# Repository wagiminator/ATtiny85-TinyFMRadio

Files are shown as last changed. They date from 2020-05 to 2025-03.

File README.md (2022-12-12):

# TinyFMRadio - FM Radio with RDS based on ATtiny45/85
TinyFMRadio is an ATtiny45/85 controlled FM radio with RDS (RDA5807) with an integrated audio amplifier (XPT8871 or TC8871), an OLED display (SSD1306) and a rotary encoder. You can directly connect a protected li-ion battery, a 3W / 4Ω speaker and an FM antenna.

- Project Video (YouTube): https://youtu.be/dG5VVQmySEc
- Design Files (EasyEDA): https://easyeda.com/wagiminator/attiny85-tinyfmradio

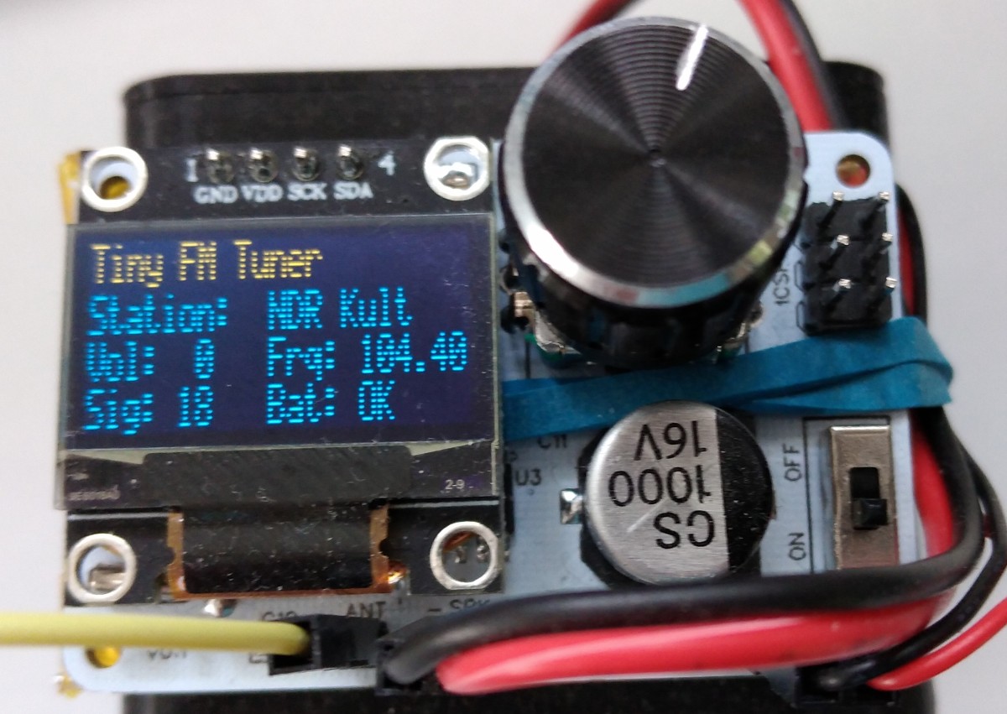
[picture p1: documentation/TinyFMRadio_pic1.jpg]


# Hardware
The low-cost RDA5807MP is a single-chip broadcast FM stereo radio tuner with fully integrated synthesizer, IF selectivity, RDS/RBDS and MPX decoder. The tuner uses the CMOS process, support multi-interface and require the least external component. All these make it very suitable for portable devices.

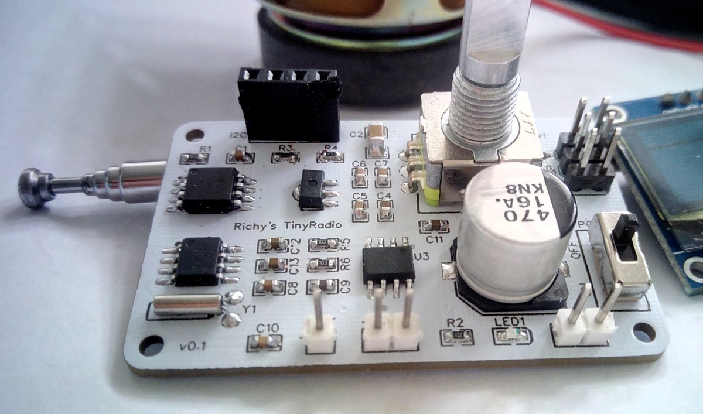
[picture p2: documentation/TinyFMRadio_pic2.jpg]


# Software
The firmware is just a demo sketch that implements basic functionality. By pressing the rotary encoder button the RDA5807 seeks the next radio station. Turning the rotary encoder increases/decreases the volume. Selected frequency and volume are stored in the EEPROM. Station name, frequency, signal strength, volume and battery state of charge are shown on an OLED display.

## I²C Implementation
The I²C protocol implementation is based on a crude bitbanging method. It was specifically designed for the limited resources of ATtiny10 and ATtiny13, but should work with some other AVRs as well. Due to the low clock frequency of the CPU, it does not require any delays for correct timing. In order to save resources, only the basic functionalities which are needed for this application are implemented. For a detailed information on the working principle of the I²C implementation visit [TinyOLEDdemo](https://github.com/wagiminator/attiny13-tinyoleddemo).

## Controlling the RDA5807
The FM tuner IC RDA5807MP is controlled via I²C by the ATtiny. It has six writable 16-bit registers (addresses 0x02 - 0x07) and six readable 16-bit registers (addresses 0x0A - 0x0F). The RDA5807 has two methods of write access, a sequential one in which the registers are always written starting from address 0x02 and an indexed method in which the register address is transferred first and then the content. Both methods are determined by different I²C addresses. To transfer the 16-bit register content, the high byte is sent first. The RDA5807 is controlled by setting or clearing certain bits in the respective registers. The details of the meanings of the individual registers can be found in the data sheet. The current register contents are saved in the RDA_regs arrays. The RDA implementation is based on the work of [Maarten Janssen](https://hackaday.io/project/9009-arduino-radio-with-rds).

## Rotary Encoder Implementation
The implementation for the rotary encoder uses pin change interrupts on only one of the pins and is written in such a way that bouncing is automatically suppressed.

## Compiling and Uploading the Software
### If using the Arduino IDE
- Make sure you have installed [ATtinyCore](https://github.com/SpenceKonde/ATTinyCore).
- Go to **Tools -> Board -> ATtinyCore** and select **ATtiny25/45/85 (No bootloader)**.
- Go to **Tools** and choose the following board options:
  - **Chip:**           ATtiny45 or ATtiny85
  - **Clock:**          1 MHz (internal)
  - **B.O.D.:**         disabled
  - Leave the rest at the default settings
- Connect your programmer to your PC and to the ICSP header of the device.
- Go to **Tools -> Programmer** and select your ISP programmer (e.g. [USBasp](https://aliexpress.com/wholesale?SearchText=usbasp)).
- Go to **Tools -> Burn Bootloader** to burn the fuses.
- Open TinyFMRadio sketch and click **Upload**.

### If using the precompiled hex-file
- Make sure you have installed [avrdude](https://learn.adafruit.com/usbtinyisp/avrdude).
- Connect your programmer to your PC and to the ICSP header of the device.
- Open a terminal.
- Navigate to the folder with the hex-file.
- Execute the following command (if necessary replace "t85" with your chip and "usbasp" with the programmer you use):
  ```
  avrdude -c usbasp -p t85 -U lfuse:w:0x62:m -U hfuse:w:0xd7:m -U efuse:w:0xff:m -U flash:w:tinyfmradio.hex
  ```

### If using the makefile (Linux/Mac)
- Make sure you have installed [avr-gcc toolchain and avrdude](http://maxembedded.com/2015/06/setting-up-avr-gcc-toolchain-on-linux-and-mac-os-x/).
- Connect your programmer to your PC and to the ICSP header of the device.
- Open a terminal.
- Navigate to the folder with the makefile and the Arduino sketch.
- Run `DEVICE=attiny85 PROGRMR=usbasp make install` to compile, burn the fuses and upload the firmware (change DEVICE and PROGRMR accordingly).

# References, Links and Notes
1. [ATtiny25/45/85 Datasheet](https://ww1.microchip.com/downloads/en/DeviceDoc/Atmel-2586-AVR-8-bit-Microcontroller-ATtiny25-ATtiny45-ATtiny85_Datasheet.pdf)
2. [RDA5807MP Datasheet](https://datasheet.lcsc.com/szlcsc/1806121226_RDA-Microelectronics-RDA5807MP_C167245.pdf)
3. [SSD1306 Datasheet](https://cdn-shop.adafruit.com/datasheets/SSD1306.pdf)
4. [TC8871 Datasheet](https://datasheet.lcsc.com/lcsc/2010160933_Shenzhen-Fuman-Elec-TC8871_C89482.pdf)
5. [ATtiny13 TinyPocketRadio](https://github.com/wagiminator/ATtiny13-TinyPocketRadio)

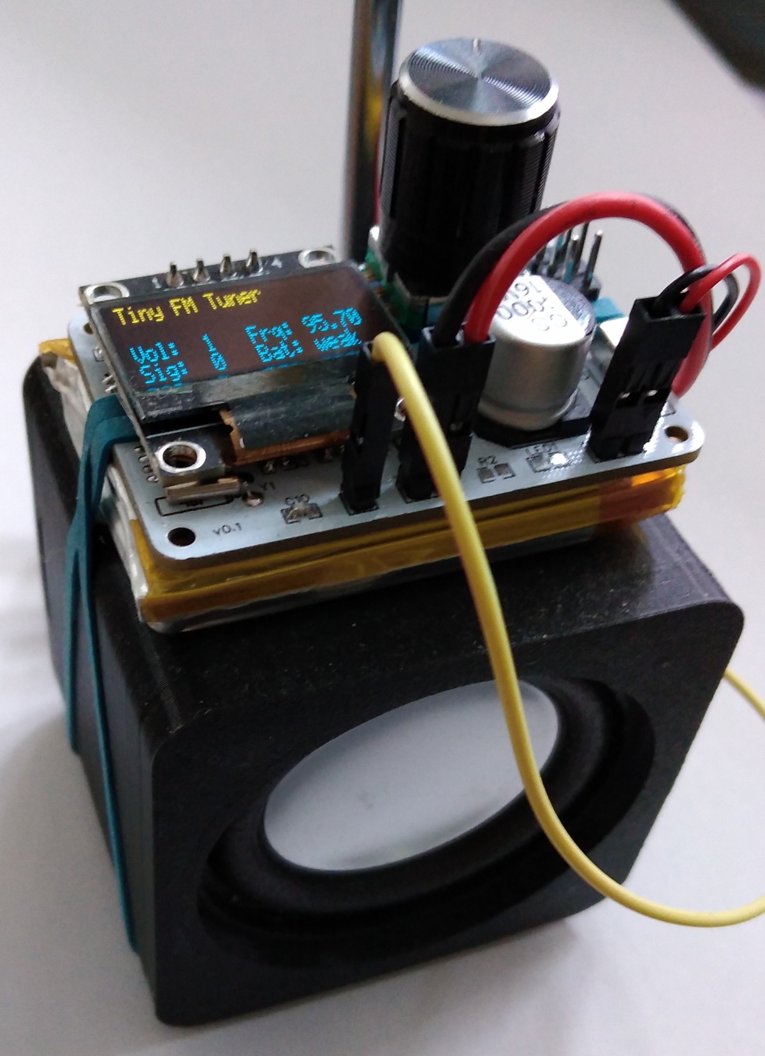
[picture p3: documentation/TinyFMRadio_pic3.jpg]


# License


This work is licensed under Creative Commons Attribution-ShareAlike 3.0 Unported License. 
(http://creativecommons.org/licenses/by-sa/3.0/)

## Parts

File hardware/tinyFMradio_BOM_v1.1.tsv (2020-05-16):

ID | Name | Designator | Footprint | Quantity | Manufacturer Part | Manufacturer | Supplier | Supplier Part | Mounted
1 | Header | VIN,SPK | HDR-1X2/2.54 | 2 | 2.54-1*2PFemale | BOOMELE | LCSC | C49661
2 | HT7333-A | U4 | SOT-89 | 1 | HT7333-A | HOLTEK | LCSC | C21583
3 | 32.768 khz | Y1 | XTAL-32KHZ | 1 | VT-200-F-32.768kHz-20PPM-6pF | Seiko | LCSC | C398715 | No
4 | I2C | I2C | HDR-4X1/2.54 | 1 | Header-Female-2.54_1x4 | ReliaPro | LCSC | C124413
5 | 1000uF | C3 | CAP-SMD_D10.0-L10.3-W10.3-H10.2 | 1 | EEE1CA471P | PANASONIC | LCSC | C336217
6 | 1k | R2 | 0603 | 1 | 0603WAF1001T5E | UniOhm | LCSC | C21190
7 | 10k | R7,R1,R8,R9 | 0603 | 4 | 0603WAF1002T5E | UniOhm | LCSC | C25804
8 | 20k | R6,R5 | 0603 | 2 | 0603WAF2002T5E | UniOhm | LCSC | C4184
9 | 4k7 | R3,R4 | 0603 | 2 | 0603WAF4701T5E | UniOhm | LCSC | C23162
10 | ATTINY85-20SU | U1 | SOIC-8_208MIL | 1 | ATTINY85-20SU | MICROCHIP | LCSC | C89852
11 | Slide Switch | POWER | SLIDE SWITCH DPDT 1P2T JB | 1 | New SchematicLib
12 | ICSP-6 | ICSP | ICSP-6 | 1 | ?
13 | Rotary Enc | SW1 | BOURNS_PEC11R-4XXXF-SXXXX | 1 | PEC11R-4015F-S0024 | BOURNS | LCSC | C143789
14 | Header | ANT | HDR-1X1/2.54 | 1 | Header-Male-2.54_1x1 | ReliaPro | LCSC | C81276
15 | 10u | C7,C4 | 0603 | 2 | CL10A106MA8NRNC | SAMSUNG | LCSC | C96446
16 | 100n | C1,C8,C15,C14,C5,C16,C6 | 0603 | 7 | CC0603KRX7R9BB104 | YAGEO | LCSC | C14663
17 | 1u | C9,C11 | 0603 | 2 | CL10A105KB8NNNC | SAMSUNG | LCSC | C15849
18 | 1n | C10 | 0603 | 1 | CL10B102KB8NNNC | SAMSUNG | LCSC | C1588
19 | 390n | C12,C13 | 0603 | 2 | CC0603KRX7R6BB394 | YAGEO | LCSC | C309480
20 | 47u | C2 | 1206 | 1 | CL31A476MQHNNNE | SAMSUNG | LCSC | C68361
21 | XPT8871ES | U3 | HSOP-8 | 1 | XPT8871ES | XPT | LCSC | C86672
22 | LED-Blue | LED1 | LED-0603 | 1 | 19-217/BHC-ZL1M2RY/3T | EVERLIGHT | LCSC | C72041
23 | RDA5807MP | U2 | SOP-8_150MIL | 1 | RDA5807MP | RDA Microelectronics | LCSC | C167245

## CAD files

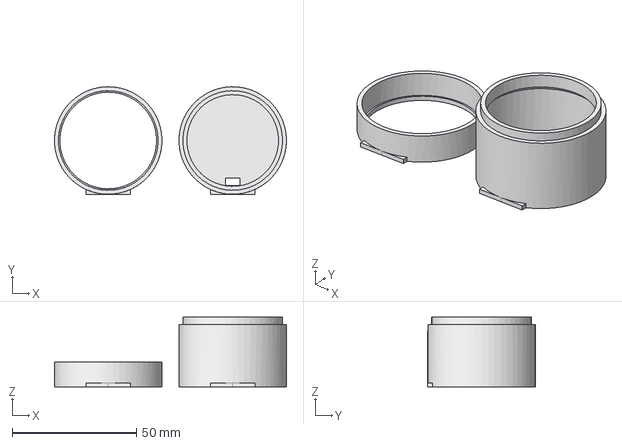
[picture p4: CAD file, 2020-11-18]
3dprint/Speaker_40mm.fcstd
93.2 x 43.2 x 28.0 mm

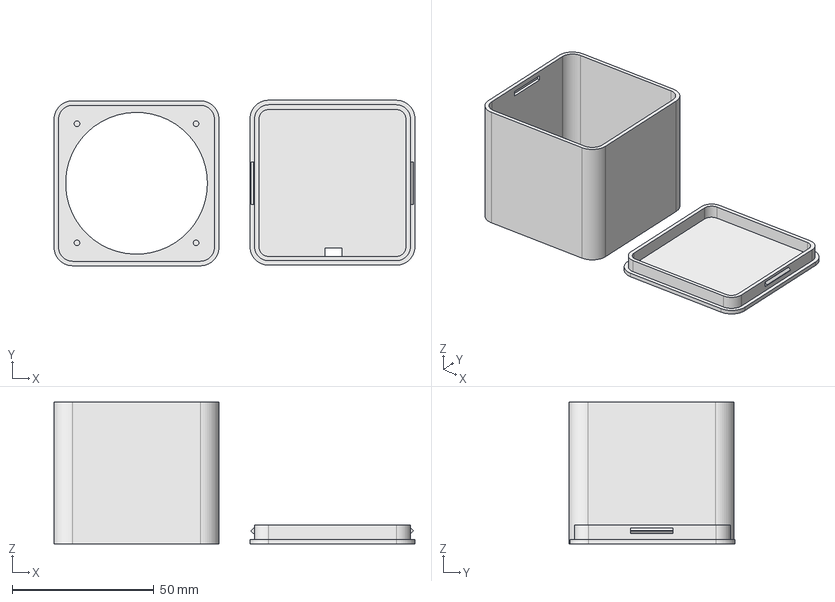
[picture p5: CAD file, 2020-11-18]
3dprint/Speaker_52mm.fcstd
127.3 x 58.4 x 50.0 mm

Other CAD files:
3dprint/Speaker_40mm.stl
3dprint/Speaker_52mm.stl

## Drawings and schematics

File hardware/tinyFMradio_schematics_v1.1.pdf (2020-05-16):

ATtiny85 Microcontroller | 3.3V Voltage Regulator | Capacitors

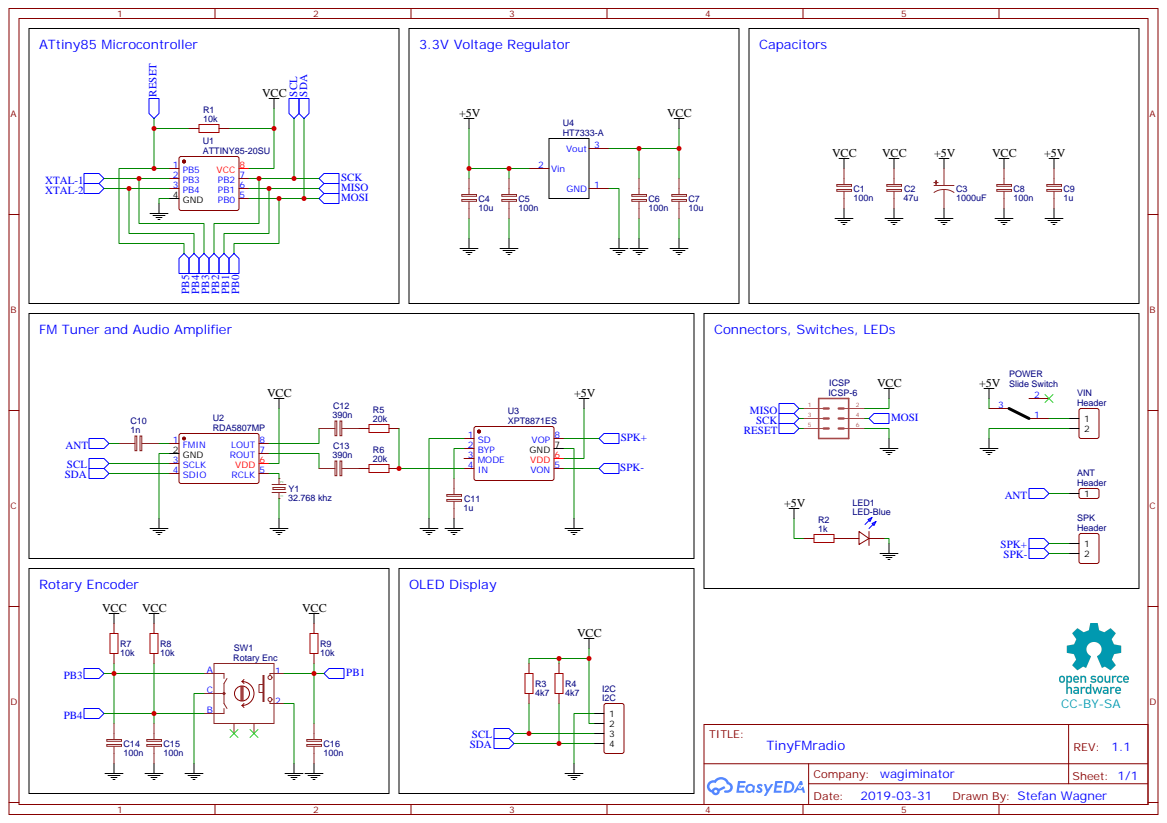
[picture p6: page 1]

Drawn By: Stefan Wagner

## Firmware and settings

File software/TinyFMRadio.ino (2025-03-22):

// ===================================================================================
// Project:   tinyFMradio - FM Tuner with RDS based on ATtiny45/85 and RDA5807
// Version:   v1.0
// Year:      2019 - 2021
// Author:    Stefan Wagner
// Github:    https://github.com/wagiminator
// EasyEDA:   https://easyeda.com/wagiminator
// License:   http://creativecommons.org/licenses/by-sa/3.0/
// ===================================================================================
//
// Description:
// ------------
// This is just a demo sketch that implements basic functionality. By pressing
// the rotary encoder button the RDA5807 seeks the next radio station. Turning
// the rotary encoder increases/decreases the volume. Selected frequency and
// volume are stored in the EEPROM. Station name, frequency, signal strength,
// volume and battery state of charge are shown on an OLED display.
//
// References:
// -----------
// RDA5807 datasheet:
// https://datasheet.lcsc.com/szlcsc/1806121226_RDA-Microelectronics-RDA5807MP_C167245.pdf
//
// SSD1306 OLED datasheet:
// https://cdn-shop.adafruit.com/datasheets/SSD1306.pdf
//
// The OLED font was adapted from Neven Boyanov and Stephen Denne:
// https://github.com/datacute/Tiny4kOLED
//
// The RDA8507 implementation was adapted from Maarten Janssen:
// https://hackaday.io/project/9009-arduino-radio-with-rds
//
// Wiring:
// -------
//                              +-\/-+
//           --- RST ADC0 PB5  1|°   |8  Vcc
// Encoder A ------- ADC3 PB3  2|    |7  PB2 ADC1 -------- OLED/RDA SCK
// Encoder B ------- ADC2 PB4  3|    |6  PB1 AIN1 OC0B --- Encoder SW
//                        GND  4|    |5  PB0 AIN0 OC0A --- OLED/RDA SDA
//                              +----+
//
// Compilation Settings:
// ---------------------
// Core:    ATtinyCore (https://github.com/SpenceKonde/ATTinyCore)
// Board:   ATtiny25/45/85 (No bootloader)
// Chip:    ATtiny 45 or ATtiny85 (depending on your chip)
// Clock:   1 MHz (internal)
// B.O.D:   disabled
//
// Leave the rest on default settings. Don't forget to "Burn bootloader"!
// No Arduino core functions or libraries are used. Use the makefile if 
// you want to compile without Arduino IDE.
//
// Fuse settings: -U lfuse:w:0x62:m -U hfuse:w:0xd7:m -U efuse:w:0xff:m


// ===================================================================================
// Libraries, Definitions and Macros
// ===================================================================================

// Libraries
#include <avr/io.h>                 // for GPIO
#include <avr/eeprom.h>             // for storing user settings into EEPROM
#include <avr/pgmspace.h>           // for reading data from program memory
#include <avr/interrupt.h>          // for interrupt functions
#include <util/delay.h>             // for delays

// Pin assignments
#define PIN_SDA       PB0           // I2C Serial Data,  connect to OLED/RDA
#define PIN_SCL       PB2           // I2C Serial Clock, connect to OLED/RDA
#define PIN_ENC_SW    PB1           // pin connected to rotary encoder switch
#define PIN_ENC_A     PB3           // pin connected to rotary encoder A
#define PIN_ENC_B     PB4           // pin connected to rotary encoder B

// EEPROM identifier
#define EEPROM_IDENT  0x6CE7        // to identify if EEPROM was written by this program

// Text strings
const char HEADER[] PROGMEM = "Tiny FM Radio v1.0";

// Variables
uint16_t  channel;                  // 0 .. 1023
uint8_t   volume = 1;               // 0 .. 15

// Pin manipulation macros
#define pinInput(x)   DDRB  &= ~(1<<(x))        // set pin to INPUT
#define pinOutput(x)  DDRB  |=  (1<<(x))        // set pin to OUTPUT
#define pinLow(x)     PORTB &= ~(1<<(x))        // set pin to LOW
#define pinHigh(x)    PORTB |=  (1<<(x))        // set pin to HIGH
#define pinPullup(x)  PORTB |=  (1<<(x))        // enable PULLUP resistor
#define pinIntEn(x)   PCMSK |=  (1<<(x))        // enable pin change interrupt
#define pinIntDis(x)  PCMSK &= ~(1<<(x))        // disable pin change interrupt
#define pinRead(x)    (PINB &   (1<<(x)))       // READ pin

// ===================================================================================
// I2C Master Implementation
// ===================================================================================

// I2C macros
#define I2C_SDA_HIGH()  pinInput(PIN_SDA)       // release SDA   -> pulled HIGH by resistor
#define I2C_SDA_LOW()   pinOutput(PIN_SDA)      // SDA as output -> pulled LOW  by MCU
#define I2C_SCL_HIGH()  pinInput(PIN_SCL)       // release SCL   -> pulled HIGH by resistor
#define I2C_SCL_LOW()   pinOutput(PIN_SCL)      // SCL as output -> pulled LOW  by MCU
#define I2C_SDA_READ()  pinRead(PIN_SDA)        // read SDA line
#define I2C_CLOCKOUT()  I2C_SCL_HIGH();I2C_SCL_LOW()  // clock out

// I2C transmit one data byte to the slave, ignore ACK bit, no clock stretching allowed
void I2C_write(uint8_t data) {
  for(uint8_t i=8; i; i--, data<<=1) {          // transmit 8 bits, MSB first
    (data&0x80)?I2C_SDA_HIGH():I2C_SDA_LOW();   // SDA depending on bit
    I2C_CLOCKOUT();                             // clock out -> slave reads the bit
  }
  I2C_SDA_HIGH();                               // release SDA for ACK bit of slave
  I2C_CLOCKOUT();                               // 9th clock pulse is for the ignored ACK bit
}

// I2C start transmission
void I2C_start(uint8_t addr) {
  I2C_SDA_LOW();                                // start condition: SDA goes LOW first
  I2C_SCL_LOW();                                // start condition: SCL goes LOW second
  I2C_write(addr);                              // send slave address
}

// I2C restart transmission
void I2C_restart(uint8_t addr) {
  I2C_SDA_HIGH();                               // prepare SDA for HIGH to LOW transition
  I2C_SCL_HIGH();                               // restart condition: clock HIGH
  I2C_start(addr);                              // start again
}

// I2C stop transmission
void I2C_stop(void) {
  I2C_SDA_LOW();                                // prepare SDA for LOW to HIGH transition
  I2C_SCL_HIGH();                               // stop condition: SCL goes HIGH first
  I2C_SDA_HIGH();                               // stop condition: SDA goes HIGH second
}

// I2C receive one data byte from the slave (ack=0 for last byte, ack>0 if more bytes to follow)
uint8_t I2C_read(uint8_t ack) {
  uint8_t data = 0;                             // variable for the received byte
  I2C_SDA_HIGH();                               // release SDA -> will be toggled by slave
  for(uint8_t i=8; i; i--) {                    // receive 8 bits
    data <<= 1;                                 // bits shifted in right (MSB first)
    I2C_SCL_HIGH();                             // clock HIGH
    if(I2C_SDA_READ()) data |= 1;               // read bit
    I2C_SCL_LOW();                              // clock LOW -> slave prepares next bit
  }
  if(ack) I2C_SDA_LOW();                        // pull SDA LOW to acknowledge (ACK)
  I2C_CLOCKOUT();                               // clock out -> slave reads ACK bit
  return data;                                  // return the received byte
}

// ===================================================================================
// OLED Implementation
// ===================================================================================

// OLED definitions
#define OLED_ADDR       0x78                    // OLED write address
#define OLED_CMD_MODE   0x00                    // set command mode
#define OLED_DAT_MODE   0x40                    // set data mode
#define OLED_INIT_LEN   9                       // length of init command array

// OLED init settings
const uint8_t OLED_INIT_CMD[] PROGMEM = {
  0xC8, 0xA1,                                   // flip screen
  0xA8, 0x1F,                                   // set multiplex ratio
  0xDA, 0x02,                                   // set com pins hardware configuration
  0x8D, 0x14,                                   // set DC-DC enable
  0xAF                                          // display on
};

// Standard ASCII 5x8 font (adapted from Neven Boyanov and Stephen Denne)
const uint8_t OLED_FONT[] PROGMEM = {
  0x00, 0x00, 0x00, 0x00, 0x00, 0x00, 0x00, 0x2F, 0x00, 0x00, 0x00, 0x07, 0x00, 0x07, 0x00,
  0x14, 0x7F, 0x14, 0x7F, 0x14, 0x24, 0x2A, 0x7F, 0x2A, 0x12, 0x23, 0x13, 0x08, 0x64, 0x62,
  0x36, 0x49, 0x55, 0x22, 0x50, 0x00, 0x05, 0x03, 0x00, 0x00, 0x00, 0x1C, 0x22, 0x41, 0x00,
  0x00, 0x41, 0x22, 0x1C, 0x00, 0x14, 0x08, 0x3E, 0x08, 0x14, 0x08, 0x08, 0x3E, 0x08, 0x08,
  0x00, 0x00, 0xA0, 0x60, 0x00, 0x08, 0x08, 0x08, 0x08, 0x08, 0x00, 0x60, 0x60, 0x00, 0x00,
  0x20, 0x10, 0x08, 0x04, 0x02, 0x3E, 0x51, 0x49, 0x45, 0x3E, 0x00, 0x42, 0x7F, 0x40, 0x00,
  0x42, 0x61, 0x51, 0x49, 0x46, 0x21, 0x41, 0x45, 0x4B, 0x31, 0x18, 0x14, 0x12, 0x7F, 0x10,
  0x27, 0x45, 0x45, 0x45, 0x39, 0x3C, 0x4A, 0x49, 0x49, 0x30, 0x01, 0x71, 0x09, 0x05, 0x03,
  0x36, 0x49, 0x49, 0x49, 0x36, 0x06, 0x49, 0x49, 0x29, 0x1E, 0x00, 0x36, 0x36, 0x00, 0x00,
  0x00, 0x56, 0x36, 0x00, 0x00, 0x08, 0x14, 0x22, 0x41, 0x00, 0x14, 0x14, 0x14, 0x14, 0x14,
  0x00, 0x41, 0x22, 0x14, 0x08, 0x02, 0x01, 0x51, 0x09, 0x06, 0x32, 0x49, 0x59, 0x51, 0x3E,
  0x7C, 0x12, 0x11, 0x12, 0x7C, 0x7F, 0x49, 0x49, 0x49, 0x36, 0x3E, 0x41, 0x41, 0x41, 0x22,
  0x7F, 0x41, 0x41, 0x22, 0x1C, 0x7F, 0x49, 0x49, 0x49, 0x41, 0x7F, 0x09, 0x09, 0x09, 0x01,
  0x3E, 0x41, 0x49, 0x49, 0x7A, 0x7F, 0x08, 0x08, 0x08, 0x7F, 0x00, 0x41, 0x7F, 0x41, 0x00,
  0x20, 0x40, 0x41, 0x3F, 0x01, 0x7F, 0x08, 0x14, 0x22, 0x41, 0x7F, 0x40, 0x40, 0x40, 0x40,
  0x7F, 0x02, 0x0C, 0x02, 0x7F, 0x7F, 0x04, 0x08, 0x10, 0x7F, 0x3E, 0x41, 0x41, 0x41, 0x3E,
  0x7F, 0x09, 0x09, 0x09, 0x06, 0x3E, 0x41, 0x51, 0x21, 0x5E, 0x7F, 0x09, 0x19, 0x29, 0x46,
  0x46, 0x49, 0x49, 0x49, 0x31, 0x01, 0x01, 0x7F, 0x01, 0x01, 0x3F, 0x40, 0x40, 0x40, 0x3F,
  0x1F, 0x20, 0x40, 0x20, 0x1F, 0x3F, 0x40, 0x38, 0x40, 0x3F, 0x63, 0x14, 0x08, 0x14, 0x63,
  0x07, 0x08, 0x70, 0x08, 0x07, 0x61, 0x51, 0x49, 0x45, 0x43, 0x00, 0x7F, 0x41, 0x41, 0x00,
  0x02, 0x04, 0x08, 0x10, 0x20, 0x00, 0x41, 0x41, 0x7F, 0x00, 0x04, 0x02, 0x01, 0x02, 0x04,
  0x40, 0x40, 0x40, 0x40, 0x40, 0x00, 0x01, 0x02, 0x04, 0x00, 0x20, 0x54, 0x54, 0x54, 0x78,
  0x7F, 0x48, 0x44, 0x44, 0x38, 0x38, 0x44, 0x44, 0x44, 0x20, 0x38, 0x44, 0x44, 0x48, 0x7F,
  0x38, 0x54, 0x54, 0x54, 0x18, 0x08, 0x7E, 0x09, 0x01, 0x02, 0x18, 0xA4, 0xA4, 0xA4, 0x7C,
  0x7F, 0x08, 0x04, 0x04, 0x78, 0x00, 0x44, 0x7D, 0x40, 0x00, 0x40, 0x80, 0x84, 0x7D, 0x00,
  0x7F, 0x10, 0x28, 0x44, 0x00, 0x00, 0x41, 0x7F, 0x40, 0x00, 0x7C, 0x04, 0x18, 0x04, 0x78,
  0x7C, 0x08, 0x04, 0x04, 0x78, 0x38, 0x44, 0x44, 0x44, 0x38, 0xFC, 0x24, 0x24, 0x24, 0x18,
  0x18, 0x24, 0x24, 0x18, 0xFC, 0x7C, 0x08, 0x04, 0x04, 0x08, 0x48, 0x54, 0x54, 0x54, 0x20,
  0x04, 0x3F, 0x44, 0x40, 0x20, 0x3C, 0x40, 0x40, 0x20, 0x7C, 0x1C, 0x20, 0x40, 0x20, 0x1C,
  0x3C, 0x40, 0x30, 0x40, 0x3C, 0x44, 0x28, 0x10, 0x28, 0x44, 0x1C, 0xA0, 0xA0, 0xA0, 0x7C,
  0x44, 0x64, 0x54, 0x4C, 0x44, 0x08, 0x36, 0x41, 0x41, 0x00, 0x00, 0x00, 0x7F, 0x00, 0x00,
  0x00, 0x41, 0x41, 0x36, 0x08, 0x08, 0x04, 0x08, 0x10, 0x08, 0xFF, 0xFF, 0xFF, 0xFF, 0xFF
};

// OLED variables
uint8_t OLED_x, OLED_y;                         // current cursor position
const uint16_t DIVIDER[] PROGMEM = {10000, 1000, 100, 10, 1}; // BCD conversion array

// OLED init function
void OLED_init(void) {
  I2C_start(OLED_ADDR);                         // start transmission to OLED
  I2C_write(OLED_CMD_MODE);                     // set command mode
  for (uint8_t i = 0; i < OLED_INIT_LEN; i++)
    I2C_write(pgm_read_byte(&OLED_INIT_CMD[i]));// send the command bytes
  I2C_stop();                                   // stop transmission
}

// OLED set the cursor
void OLED_setCursor(uint8_t xpos, uint8_t ypos) {
  I2C_start(OLED_ADDR);                         // start transmission to OLED
  I2C_write(OLED_CMD_MODE);                     // set command mode
  I2C_write(xpos & 0x0F);                       // set low nibble of start column
  I2C_write(0x10 | (xpos >> 4));                // set high nibble of start column
  I2C_write(0xB0 | (ypos & 0x07));              // set start page
  I2C_stop();                                   // stop transmission
  OLED_x = xpos; OLED_y = ypos;                 // set the cursor variables
}

// OLED clear rest of the current line
void OLED_clearLine(void) {
  I2C_start(OLED_ADDR);                         // start transmission to OLED
  I2C_write(OLED_DAT_MODE);                     // set data mode
  while(OLED_x++ < 128) I2C_write(0);           // clear rest of the line
  I2C_stop();                                   // stop transmission
  if(++OLED_y > 3) OLED_y = 0;                  // calculate next line
  OLED_setCursor(0, OLED_y);                    // set cursor to start of next line
}

// OLED clear screen
void OLED_clearScreen(void) {
  OLED_setCursor(0, 0);                         // set cursor to home position
  for(uint8_t i=4; i; i--) OLED_clearLine();    // clear all 4 lines
}

// OLED plot a single character
void OLED_plotChar(char c) {
  uint16_t ptr = c - 32;                        // character pointer
  ptr += ptr << 2;                              // -> ptr = (ch - 32) * 5;
  I2C_write(0x00);                              // write space between characters
  for (uint8_t i=5 ; i; i--) I2C_write(pgm_read_byte(&OLED_FONT[ptr++]));
  OLED_x += 6;                                  // update cursor
  if (OLED_x > 122) {                           // line end ?
    I2C_stop();                                 // stop data transmission
    OLED_setCursor(0,++OLED_y);                 // set next line start
    I2C_start(OLED_ADDR);                       // start transmission to OLED
    I2C_write(OLED_DAT_MODE);                   // set data mode
  }
}

// OLED print a string
void OLED_printStr(uint8_t* str) {
  I2C_start(OLED_ADDR);                         // start transmission to OLED
  I2C_write(OLED_DAT_MODE);                     // set data mode
  while(*str) OLED_plotChar(*str++);            // plot each character
  I2C_stop();                                   // stop transmission
}

// OLED print a string from program memory
void OLED_print(const char* p) {
  I2C_start(OLED_ADDR);                         // start transmission to OLED
  I2C_write(OLED_DAT_MODE);                     // set data mode
  char ch = pgm_read_byte(p);                   // read first character from program memory
  while (ch) {                                  // repeat until string terminator
    OLED_plotChar(ch);                          // print character on OLED
    ch = pgm_read_byte(++p);                    // read next character
  }
  I2C_stop();                                   // stop transmission
}

// OLED print a string from program memory with new line
void OLED_println(const char* p) {
  OLED_print(p);
  OLED_clearLine();
}

// OLED print 8-bit value as 2-digit decimal (BCD conversion by subtraction method)
void OLED_printVal(uint8_t value) {
  if(value > 99) value = 99;                    // limit 2-digit value
  I2C_start(OLED_ADDR);                         // start transmission to OLED
  I2C_write(OLED_DAT_MODE);                     // set data mode
  uint8_t digitval = 0;                         // start with digit value 0
  while(value >= 10) {                          // if current divider fits into the value
    digitval++;                                 // increase digit value
    value -= 10;                                // decrease value by divider
  }
  if(digitval) OLED_plotChar(digitval + '0');   // print first digit
  else OLED_plotChar(' ');                      // leading space if zero
  OLED_plotChar(value + '0');                   // print second digit
  I2C_stop();                                   // stop transmission
}

// OLED print frequency (BCD conversion by subtraction method)
void OLED_printFrequency(uint16_t value) {
  uint8_t leadflag = 0;                         // flag for leading spaces
  I2C_start(OLED_ADDR);                         // start transmission to OLED
  I2C_write(OLED_DAT_MODE);                     // set data mode
  for(uint8_t digit = 0; digit < 5; digit++) {  // 5 digits
    uint8_t digitval = 0;                       // start with digit value 0
    uint16_t divider = pgm_read_word(&DIVIDER[digit]); // current divider
    while(value >= divider) {                   // if current divider fits into the value
      leadflag = 1;                             // end of leading spaces
      digitval++;                               // increase digit value
      value -= divider;                         // decrease value by divider
    }
    if(leadflag || (digit > 1)) OLED_plotChar(digitval + '0'); // print the digit
    else OLED_plotChar(' ');                    // or print leading space
    if(digit == 2) OLED_plotChar('.');          // print decimal after 3rd digit
  }
  I2C_stop();                                   // stop transmission
}

// ===================================================================================
// RDA5807 Implementation
// ===================================================================================

// RDA definitions
#define RDA_ADDR_SEQ    0x20                    // RDA I2C write address for sequential access
#define RDA_ADDR_INDEX  0x22                    // RDA I2C write address for indexed access
#define RDA_VOL         1                       // start volume

// RDA register definitions
enum{ RDA_REG_2, RDA_REG_3, RDA_REG_4, RDA_REG_5, RDA_REG_6, RDA_REG_7 };
enum{ RDA_REG_A, RDA_REG_B, RDA_REG_C, RDA_REG_D, RDA_REG_E, RDA_REG_F };
uint16_t RDA_read_regs[6];                      // RDA registers for reading
uint16_t RDA_write_regs[6] = {                  // RDA registers for writing:
  0b1101001000001101,                           // RDA register 0x02 preset
  0b0001010111000000,                           // RDA register 0x03 preset
  0b0000101000000000,                           // RDA register 0x04 preset
  0b1000100010000000,                           // RDA register 0x05 preset
  0b0000000000000000,                           // RDA register 0x06 preset
  0b0000000000000000                            // RDA register 0x07 preset
};

// RDA state macros
#define RDA_hasRdsData        ( RDA_read_regs[RDA_REG_A] & 0x8000 )
#define RDA_isTuning          (~RDA_read_regs[RDA_REG_A] & 0x4000 )
#define RDA_tuningError       ( RDA_read_regs[RDA_REG_A] & 0x2000 )
#define RDA_hasRdsBlockE      ( RDA_read_regs[RDA_REG_A] & 0x0800 )
#define RDA_isStereo          ( RDA_read_regs[RDA_REG_A] & 0x0400 )
#define RDA_channel           ( RDA_read_regs[RDA_REG_A] & 0x03FF )
#define RDA_isTunedToChannel  ( RDA_read_regs[RDA_REG_B] & 0x0100 )
#define RDA_rdsBlockE         ( RDA_read_regs[RDA_REG_B] & 0x0010 )
#define RDA_rdsBlockErrors    ( RDA_read_regs[RDA_REG_B] & 0x000F )
#define RDA_signalStrength    ((RDA_read_regs[RDA_REG_B] & 0xFE00 ) >> 8 )

// RDA variables
uint8_t RDA_stationName[9];                     // string for the station name
uint8_t RDA_rdsStationName[8];                  // just for internal use

// RDA write specified register
void RDA_writeReg(uint8_t reg) {
  I2C_start(RDA_ADDR_INDEX);                    // start I2C for index write to RDA
  I2C_write(0x02 + reg);                        // set the register to write
  I2C_write(RDA_write_regs[reg] >> 8);          // send high byte
  I2C_write(RDA_write_regs[reg]);               // send low byte
  I2C_stop();                                   // stop I2C
}
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
int main(void) { 
  // Setup  
  ADC_init();                                   // setup ADC
  ENC_init();                                   // setup rotary encoder
  sei();                                        // enable global interrupts

  // Disable unused peripherals to save power
  ACSR =  (1<<ACD);                             // disable analog comperator
  PRR  =  (1<<PRADC)                            // shut down ADC
       |  (1<<PRUSI)                            // shut down USI
       |  (1<<PRTIM0)                           // shut down timer0
       |  (1<<PRTIM1);                          // shut down timer1

  // Prepare and start OLED
  OLED_init();
  OLED_clearScreen();
  OLED_println(HEADER);
  OLED_print(PSTR("Starting ..."));

  // Start the tuner
  RDA_init();
  if(EEPROM_get()) RDA_setChannel(channel);
  else RDA_seekUp();
  ENC_set(0, 15, 1, volume);
  RDA_setVolume(volume);
  RDA_waitTuning();

  // Loop
  while(1) {
    // Update information on OLED
    RDA_updateStatus();
    uint8_t vcc = ADC_readVcc();
    OLED_setCursor(0, 1);
    OLED_print(PSTR("Station:  "));
    OLED_printStr(RDA_stationName);
    OLED_clearLine();
    OLED_print(PSTR("Vol: "));
    OLED_printVal(volume);
    OLED_print(PSTR("   Frq: "));
    OLED_printFrequency(RDA_getFrequency());
    OLED_print(PSTR("Sig: "));
    OLED_printVal(RDA_signalStrength);
    OLED_print(PSTR("   Bat: "));
    if(vcc < 32) OLED_println(PSTR("weak"));
    else OLED_println(PSTR("OK"));

    // Check rotary encoder switch for channel seek
    if (!pinRead(PIN_ENC_SW)) {                 // seek up if encoder button is pressed
      OLED_setCursor(0, 1);
      OLED_println(PSTR("Tuning ..."));
      OLED_clearLine(); OLED_clearLine();
      RDA_seekUp();
      RDA_waitTuning();
      while (!pinRead(PIN_ENC_SW));
      EEPROM_update();
    }

    // Check rotary encoder for volume change
    if (volume != ENC_get()) {                  // change volume if encoder was turned
      volume = ENC_get();
      RDA_setVolume(volume);
      EEPROM_update();
    }
  }
}

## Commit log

2020-11-18 Update files
    [Speaker_40mm.fcstd, Speaker_40mm.stl, Speaker_52mm.fcstd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]
2025-03-06 fix: wrong signal strength (RSSI) value read
    [TinyFMRadio.ino]
